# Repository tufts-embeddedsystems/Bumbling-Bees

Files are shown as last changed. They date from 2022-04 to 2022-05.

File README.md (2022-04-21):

# Bumbling-Bees

Contributors: Max Ramer, Brandon Gray, Melinda Burns, Alina Shah, Arnav Gupta, Muheng Shen

## Goal

Design, build, and program 10 temperature sensor nodes to measure temperature once an hour.  Nodes should last 6 months in the field.

## Roles

Hardware Engineers: Muheng & Arnav

Firmware Engineers: Brandon & Max

Software Engineers: Mels & Alina

## Tasks

#### Hardware

- [ ] Create an acceptance testing plan. Must test:
  
  - [ ] Sensor and thermistor
  
  - [ ] Remaining battery life
  
  - [ ] WiFi capability

- [ ] Build 1 PCB dev board

- [ ] Verify dev board functionality with testing plan

- [ ] Build and test 10 PCB dev boards

#### Firmware

- [ ] Design main program execution loop

- [ ] Collaborate with software team to finish demos

- [ ] Collaborate with hardware team to develop acceptance tests using software team demos

#### Software

- [ ] Finalize demos with firmware team:
  
  - [ ] Sensor and thermistor
  
  - [ ] Remaining battery life
  
  - [ ] WiFi & MQTT

- [ ] Write program execution loop

- [ ] Setup web server-side HTML to test MQTT messages

## 

## File structure

- `hardware/`
  
  - `pcb/`
    
    - `devboard_final/`: all KiCad files for development of the temperature node PCB. Also includes Gerber files.
  
  - `testing_plan/`: documentation for acceptance tests necessary to ensure correct PCB design.

- `PlatformIO/`: necessary files for dev environment

- `software/`
  
  - `demo/`: all code to demo individual functionality (i.e. measure temperature, connect to WiFi, enter deep sleep)
  
  - `libs/`: any necessary libraries for development
    
    `main/`: main program execution code for a node. Encompasses all demos.

## Program Execution



## Status Updates

#### Tuesday 4/26

#### Thursday 4/28

#### ...

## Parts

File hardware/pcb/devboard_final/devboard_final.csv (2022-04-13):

Source: | /Users/maxramer/Documents/Tufts/EE193/Bumbling-Bees/pcb_design/Prototype MKI/32S2_3/32S2_3.kicad_sch
Date: | Wednesday, April 13, 2022 at 10:00:36 AM
Tool: | Eeschema (6.0.1-0)
Generator: | /Applications/KiCad/KiCad.app/Contents/SharedSupport/plugins/bom_csv_grouped_by_value.py
Component Count: | 16
Individual Components:
Item | Qty | Reference(s) | Value | LibPart | Footprint | Datasheet
 |  | C1 | 10u | Device:C | Capacitor_SMD:C_0805_2012Metric_Pad1.18x1.45mm_HandSolder | ~
 |  | C2 | 0.1u | Device:C | Capacitor_SMD:C_0805_2012Metric_Pad1.18x1.45mm_HandSolder | ~
 |  | C3 | 10u | Device:C | Capacitor_SMD:C_0805_2012Metric_Pad1.18x1.45mm_HandSolder | ~
 |  | C4 | 10u | Device:C | Capacitor_SMD:C_0805_2012Metric_Pad1.18x1.45mm_HandSolder | ~
 |  | C6 | 1u | Device:C | Capacitor_SMD:C_0805_2012Metric_Pad1.18x1.45mm_HandSolder | ~
 |  | J1 | Conn_01x08 | Connector_Generic:Conn_01x08 | Connector_PinHeader_1.00mm:PinHeader_1x08_P1.00mm_Vertical | ~
 |  | L1 | 2.2u | Device:L | Inductor_SMD:L_0805_2012Metric_Pad1.05x1.20mm_HandSolder | ~
 |  | R1 | 10kΩ | Device:R_US | Resistor_SMD:R_0805_2012Metric_Pad1.20x1.40mm_HandSolder | ~
 |  | R2 | 10kΩ | Device:R_US | Resistor_SMD:R_0805_2012Metric_Pad1.20x1.40mm_HandSolder | ~
 |  | R3 | 10kΩ | Device:R_US | Resistor_SMD:R_0805_2012Metric_Pad1.20x1.40mm_HandSolder | ~
 |  | R4 | 10kΩ | Device:R_US | Resistor_SMD:R_0805_2012Metric_Pad1.20x1.40mm_HandSolder | ~
 |  | R5 | 10k | Device:R | Resistor_SMD:R_0805_2012Metric_Pad1.20x1.40mm_HandSolder | ~
 |  | U1 | AT30TS74 | Temp Sensors:AT30TS74 | Package_SO:SOIC-8_3.9x4.9mm_P1.27mm
 |  | U2 | NCU18XH103F60RB | Temp Sensors:NCU18XH103F60RB | Resistor_SMD:R_0805_2012Metric_Pad1.20x1.40mm_HandSolder
 |  | U3 | ESP32_S2_SOLO | CPU:ESP32_S2_SOLO | Module:ESP-32-S2-SOLO
 |  | U4 | RP402N331F-TR-FE | power:RP402N331F-TR-FE | Module:RP402N331F-TR-FE
Collated Components:
Item | Qty | Reference(s) | Value | LibPart | Footprint | Datasheet
1 | 3 | C1, C3, C4 | 10u | Device:C | Capacitor_SMD:C_0805_2012Metric_Pad1.18x1.45mm_HandSolder | ~
2 | 1 | C2 | 0.1u | Device:C | Capacitor_SMD:C_0805_2012Metric_Pad1.18x1.45mm_HandSolder | ~
3 | 1 | C6 | 1u | Device:C | Capacitor_SMD:C_0805_2012Metric_Pad1.18x1.45mm_HandSolder | ~
4 | 1 | J1 | Conn_01x08 | Connector_Generic:Conn_01x08 | Connector_PinHeader_1.00mm:PinHeader_1x08_P1.00mm_Vertical | ~
5 | 1 | L1 | 2.2u | Device:L | Inductor_SMD:L_0805_2012Metric_Pad1.05x1.20mm_HandSolder | ~
6 | 4 | R1, R2, R3, R4 | 10kΩ | Device:R_US | Resistor_SMD:R_0805_2012Metric_Pad1.20x1.40mm_HandSolder | ~
7 | 1 | R5 | 10k | Device:R | Resistor_SMD:R_0805_2012Metric_Pad1.20x1.40mm_HandSolder | ~
8 | 1 | U1 | AT30TS74 | Temp Sensors:AT30TS74 | Package_SO:SOIC-8_3.9x4.9mm_P1.27mm
9 | 1 | U2 | NCU18XH103F60RB | Temp Sensors:NCU18XH103F60RB | Resistor_SMD:R_0805_2012Metric_Pad1.20x1.40mm_HandSolder
10 | 1 | U3 | ESP32_S2_SOLO | CPU:ESP32_S2_SOLO | Module:ESP-32-S2-SOLO
11 | 1 | U4 | RP402N331F-TR-FE | power:RP402N331F-TR-FE | Module:RP402N331F-TR-FE

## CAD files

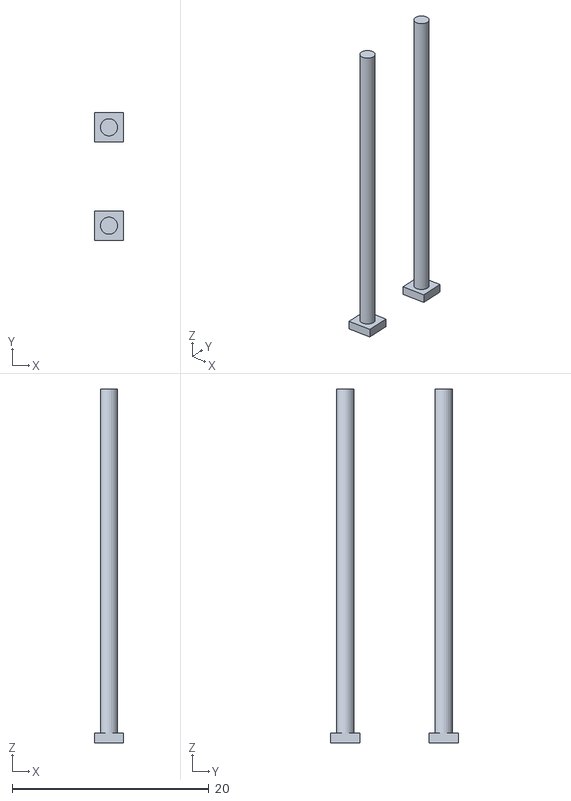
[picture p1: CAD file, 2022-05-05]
diagrams/193SencorPackaging_V2 Pins.stl
3.00 x 13.0 x 36.0

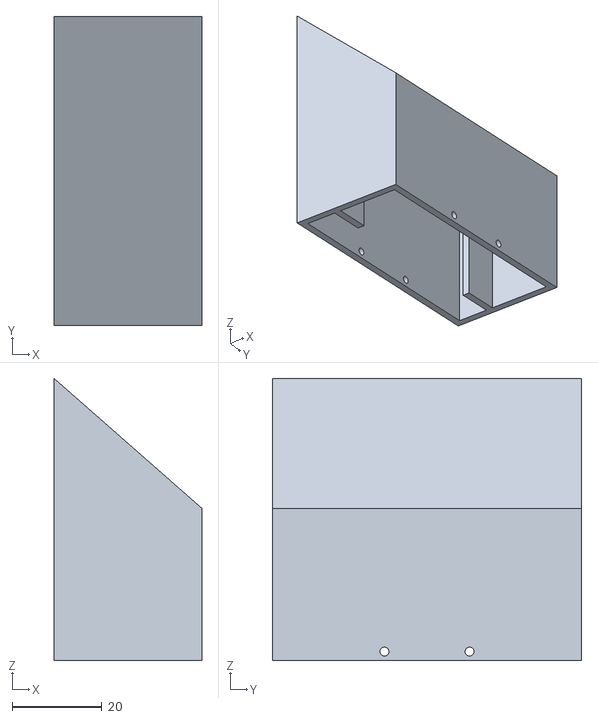
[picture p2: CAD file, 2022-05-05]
diagrams/193SencorPackaging_V2 Body.stl
33.0 x 69.0 x 63.0

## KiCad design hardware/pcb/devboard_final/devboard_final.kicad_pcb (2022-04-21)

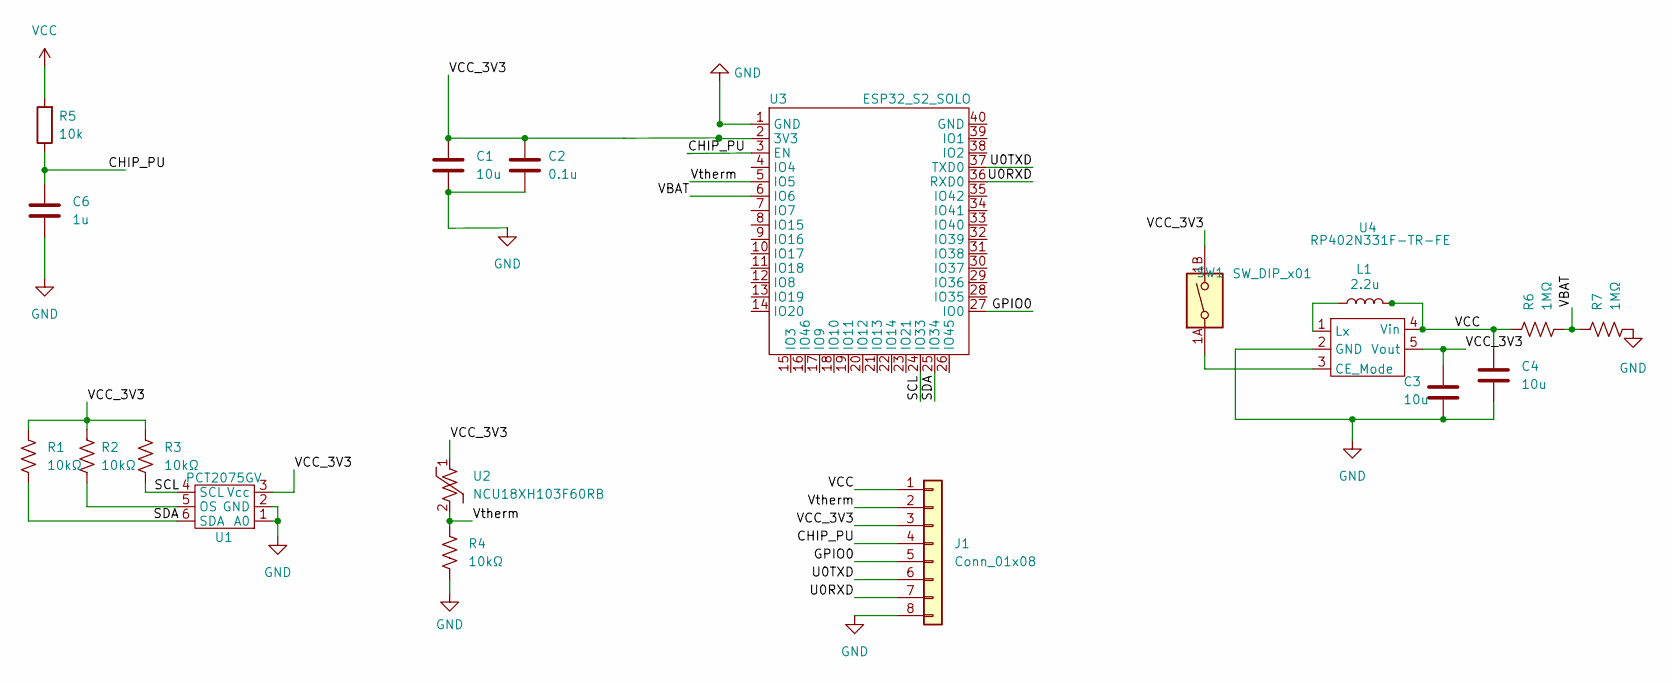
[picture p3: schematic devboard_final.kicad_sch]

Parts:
C1, C3, C4: 10u; C_0805_2012Metric_Pad1.18x1.45mm_HandSolder
C2: 0.1u; C_0805_2012Metric_Pad1.18x1.45mm_HandSolder
C6: 1u; C_0805_2012Metric_Pad1.18x1.45mm_HandSolder
J1: Conn_01x08; PinHeader_1x08_P2.54mm_Vertical
L1: 2.2u; L_0805_2012Metric_Pad1.05x1.20mm_HandSolder
R1, R2, R3, R4: 10kΩ; R_0805_2012Metric_Pad1.20x1.40mm_HandSolder
R5: 10k; R_0805_2012Metric_Pad1.20x1.40mm_HandSolder
R6, R7: 1MΩ; R_0805_2012Metric_Pad1.20x1.40mm_HandSolder
SW1: SW_DIP_x01; SW_DS04-254-1-01BK-SMT
U1: PCT2075GV; TSOP-6_1.65x3.05mm_P0.95mm
U2: NCU18XH103F60RB; R_0805_2012Metric_Pad1.20x1.40mm_HandSolder
U3: ESP32_S2_SOLO; ESP-32-S2-SOLO
U4: RP402N331F-TR-FE; SOT-23-5

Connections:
/CHIP_PU: C6.1, J1.4, R5.1, U3.3 (EN)
/GPIO0: J1.5, U3.27 (IO0)
/SCL: R3.2, U1.4 (SCL), U3.24 (IO33)
/SDA: R1.2, U1.6 (SDA), U3.25 (IO34)
/U0RXD: J1.7, U3.36 (RXD0)
/U0TXD: J1.6, U3.37 (TXD0)
/VBAT: R6.2, R7.1, U3.6 (IO6)
/VCC_3V3: C3.2, J1.3, R1.1, R2.1, R3.1, SW1.1B, U1.3 (Vcc), U2.1, U4.5 (Vout)
/Vtherm: J1.2, R4.1, U2.2, U3.5 (IO5)
GND: C1.2, C2.2, C3.1, C4.2, C6.2, J1.8, R4.2, R7.2, U1.1 (A0), U1.2 (GND), U3.1 (GND), U4.2 (GND)
unnamed: C1.1, C2.1, U3.2 (3V3)
unnamed: L1.1, U4.1 (Lx)
unnamed: R2.2, U1.5 (OS)
unnamed: SW1.1A, U4.3 (CE_Mode)
VCC: C4.1, J1.1, L1.2, R5.2, R6.1, U4.4 (Vin)

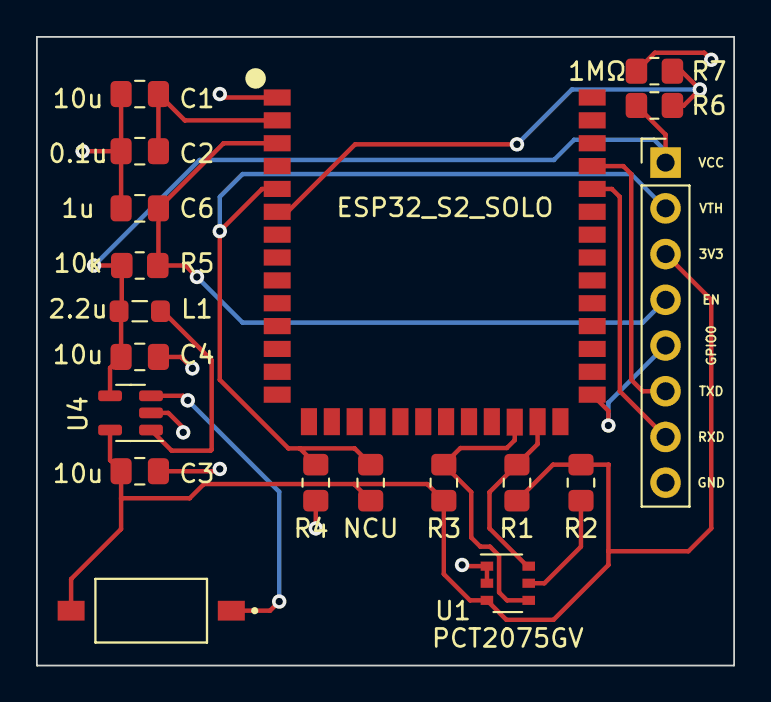
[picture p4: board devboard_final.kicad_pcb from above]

Board: 2 copper layers, 38.7 x 34.9 mm, 19 parts (0 on the bottom side), 15 nets.

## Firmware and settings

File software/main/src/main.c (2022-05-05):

// Bumbling Bees temperature sensor code
// Embedded Systems, spring 2022

#include "freertos/FreeRTOS.h"
#include "freertos/task.h"
#include "nvs_flash.h"
#include "esp_netif.h"
#include "mqtt_client.h"
#include "minimal_wifi.h"
#include "esp_sleep.h"
#include "esp_log.h"
#include <stdio.h>
#include <stdlib.h>
#include <math.h>
#include "driver/adc.h"
#include "driver/i2c.h"
#include "esp_adc_cal.h"

// Address of MQTT server
#define BROKER_URI "mqtt://en1-pi.eecs.tufts.edu"
#define NODE_PATH "nodes/bumbling-bees/node2"

//I2C SENSOR//
#define I2C_MASTER_SCL_IO           33      /*!< GPIO number used for I2C master clock */
#define I2C_MASTER_SDA_IO           34     /*!< GPIO number used for I2C master data  */
#define I2C_MASTER_NUM              0                          /*!< I2C master i2c port number, the number of i2c peripheral interfaces available will depend on the chip */
#define I2C_MASTER_FREQ_HZ          400000                     /*!< I2C master clock frequency */
#define I2C_MASTER_TX_BUF_DISABLE   0                          /*!< I2C master doesn't need buffer */
#define I2C_MASTER_RX_BUF_DISABLE   0                          /*!< I2C master doesn't need buffer */
#define I2C_MASTER_TIMEOUT_MS       1000
#define ACK_CHECK_EN 0x1                        /*!< I2C master will check ack from slave*/
#define ACK_VAL 0x0                             /*!< I2C ack value */
#define NACK_VAL 0x1                            /*!< I2C nack value */
#define SENSOR_ADDR                 0x93        /*!< Slave address of the temp sensor  1001 001*/

//THERMISTOR ADC//
#define DEFAULT_VREF 1100
#define NO_OF_SAMPLES 64 //Taking 64 samples per reading
static esp_adc_cal_characteristics_t *adc_chars;
static const adc_channel_t channel = ADC_CHANNEL_4;
static const adc_bits_width_t width = ADC_WIDTH_BIT_13;
static const adc_atten_t atten = ADC_ATTEN_DB_11;
static const adc_unit_t unit = ADC_UNIT_1;
#define T0 298.15 //Room Temp in Kelvin
#define R0 10000 //Resitor used in voltage divider
#define ThermBeta 3380.0 //Beta Constant 

//BATTERY ADC//
/*
static const adc_channel_t batt_channel = ADC_CHANNEL_5;
#define BATT_MAX_VOLTAGE 3.6
*/

// Data packet
struct packet {
	int64_t time; // Epoch time
	int32_t sensor_temp; // Temperature in C, multiplied by 1000
	int32_t thermistor_temp; // Temp in degrees C, -2^31 is unused
	uint8_t battery; // Percentage of battery capacity, 0 to 100, 255 means no battery or no measurement
	uint16_t data_len; // 0 for us
	//uint8_t teamdata[2];
} __attribute__((packed));

const int PACKET_SIZE = 8 + 4 + 4 + 1 + 2;

// Function declarations
void wifi_init(void);
static void mqtt_event_handler(void *handler_args, esp_event_base_t base, int32_t event_id, void *event_data);
uint8_t myPow(uint8_t base, uint8_t exponent);
static esp_err_t i2c_master_init(void);
static esp_err_t temp_register_read(uint8_t *data, size_t len);
float convertTemp(uint8_t data[]);
void config_ADC(void);


void app_main() {
    // Start I2C and ADC
    i2c_master_init();
    config_ADC();

    // Start wifi
    wifi_init();

    // Initialize MQTT client
    esp_mqtt_client_config_t mqtt_cfg = {
        .uri = BROKER_URI,
    };
    esp_mqtt_client_handle_t client = esp_mqtt_client_init(&mqtt_cfg);
    esp_mqtt_client_register_event(client, ESP_EVENT_ANY_ID, mqtt_event_handler, client);

    // Start the client
    esp_mqtt_client_start(client);

}


// Does some magic to make the wifi work
void wifi_init(void) {
    // `ESP_ERROR_CHECK` is a macro which checks that the return value of a function is
    // `ESP_OK`.  If not, it prints some debug information and aborts the program.

    // Enable Flash (aka non-volatile storage, NVS)
    // The WiFi stack uses this to store some persistent information
    ESP_ERROR_CHECK(nvs_flash_init());

    // Initialize the network software stack
    ESP_ERROR_CHECK(esp_netif_init());

    // Initialize the event loop, a separate thread which checks for events
    // (like WiFi being connected or receiving an MQTT message) and dispatches
    // functions to handle them.
    ESP_ERROR_CHECK(esp_event_loop_create_default());

    // Now connect to WiFi
    ESP_ERROR_CHECK(example_connect());
}


// Decides what to do when an MQTT event happens
static void mqtt_event_handler(void *handler_args, esp_event_base_t base, int32_t event_id, void *event_data)
{
    const char *TAG = "MQTT_HANDLE";
    ESP_LOGD(TAG, "Event dispatched from event loop base=%s, event_id=%d", base, event_id);
    esp_mqtt_event_handle_t event = event_data;
    esp_mqtt_client_handle_t client = event->client;
    int msg_id;
    switch ((esp_mqtt_event_id_t)event_id) {

    // Send message once connected
    case MQTT_EVENT_CONNECTED:
        ESP_LOGI(TAG, "MQTT_EVENT_CONNECTED");

        // Get IC temperature readings
        uint8_t IC_data[2];
        float IC_Temp;
        ESP_ERROR_CHECK(temp_register_read(IC_data, 2)); 
        printf("IC Temp = %d + %d\n", IC_data[0], IC_data[1]);
        IC_Temp = convertTemp(IC_data);
        printf("IC Temp = %f ˚C\n",IC_Temp);
        int ic_convert_temp = IC_Temp * 1000;
        // make sure to change the variable back

        // Get ADC temperature readings
        float ThermRes = 0;
        float ThermTempK = 0;
        float ThermTempC = 0;
        uint32_t thermReading = 0;

        for (int i = 0; i < NO_OF_SAMPLES; i++) {
            thermReading += adc1_get_raw((adc1_channel_t)channel);
        }
        thermReading /= NO_OF_SAMPLES;

        // Convert adc_reading to voltage in mV
        float voltage = esp_adc_cal_raw_to_voltage(thermReading, adc_chars);
        ThermRes = R0 * ((3300/voltage)-1);

        // Test #1 (Approx Temperature)
        ThermTempK = 1/((1/T0) + ((1/ThermBeta) * log(ThermRes/R0)));
        ThermTempC = ThermTempK - 273.15;
        printf("Temp Approx: %f K = %f ˚C\n", ThermTempK, ThermTempC);
        int therm_convert_temp = ThermTempC * 1000;

        // Get battery voltage
        /*
        int32_t battReading = 0;
        for (int i = 0; i < NO_OF_SAMPLES; i++) {
            battReading += adc1_get_raw((adc1_channel_t)batt_channel);
        }
        battReading /= NO_OF_SAMPLES;
        float batt_voltage = esp_adc_cal_raw_to_voltage(battReading, adc_chars);
        batt_voltage = ((batt_voltage * 2) / BATT_MAX_VOLTAGE) * 100; // Adjust for divider and convert to percentage
        uint8_t batt_life = batt_voltage;
        */

        // Construct packet
        struct packet data_packet = {1, ic_convert_temp, therm_convert_temp, 100, 0};
        void *data_ptr = &data_packet;

        // Send the message
        msg_id = esp_mqtt_client_publish(client, NODE_PATH, (char *)data_ptr, PACKET_SIZE, 1, 0);
        ESP_LOGI(TAG, "sent publish successful, msg_id=%d", msg_id);

        break;

    // Disconnect + go back to sleep once acknowledgement of publish recieved
    case MQTT_EVENT_PUBLISHED:
        ESP_LOGI(TAG, "MQTT_EVENT_PUBLISHED, msg_id=%d", event->msg_id);

        // Disconnect from wifi and MQTT client
        ESP_ERROR_CHECK(esp_mqtt_client_disconnect(client));
        ESP_ERROR_CHECK(example_disconnect());

        // Sleep
        uint64_t microseconds = 1000000;
        uint64_t seconds = 3600;
        uint64_t sleep_time = seconds * microseconds;
        esp_sleep_enable_timer_wakeup(sleep_time);
        esp_deep_sleep_start();
        break;

    // Log event before connect to prevent suspicious event message
    case MQTT_EVENT_BEFORE_CONNECT:
        ESP_LOGI(TAG, "MQTT_EVENT_BEFORE_CONNECT");
        break;

    // Handle other events
    default:
        ESP_LOGI(TAG, "Other event id:%d", event->event_id);
        break;
    }
}

uint8_t myPow (uint8_t base, uint8_t exponent) {

    uint8_t result = 1;

    for (uint8_t i = 0; i < exponent; i++) {
        result *= base;
    }

    return result;
}

/**
 * @brief i2c master initialization
 */
static esp_err_t i2c_master_init(void)
{
    int i2c_master_port = I2C_MASTER_NUM;

    i2c_config_t conf = {
        .mode = I2C_MODE_MASTER,
        .sda_io_num = I2C_MASTER_SDA_IO,
        .scl_io_num = I2C_MASTER_SCL_IO,
        .sda_pullup_en = GPIO_PULLUP_ENABLE,
        .scl_pullup_en = GPIO_PULLUP_ENABLE,
        .master.clk_speed = I2C_MASTER_FREQ_HZ,
    };

    i2c_param_config(i2c_master_port, &conf);

    return i2c_driver_install(i2c_master_port, conf.mode, I2C_MASTER_RX_BUF_DISABLE, I2C_MASTER_TX_BUF_DISABLE, 0);
}

/**
 * @brief Read a sequence of bytes from a temp sensor registers
 */
static esp_err_t temp_register_read(uint8_t *data, size_t len)
{   
    i2c_cmd_handle_t cmd = i2c_cmd_link_create();
    i2c_master_start(cmd);
    i2c_master_write_byte(cmd, SENSOR_ADDR, ACK_CHECK_EN); //0x93 is the slave address hardcoded (the 1 in the LSB tells that it's a read)
    if (len > 1) {
        i2c_master_read(cmd, data, len - 1, ACK_VAL);
    }
    i2c_master_read_byte(cmd, data + len - 1, NACK_VAL);
    i2c_master_stop(cmd);
    esp_err_t ret = i2c_master_cmd_begin(I2C_MASTER_NUM, cmd, I2C_MASTER_TIMEOUT_MS / portTICK_PERIOD_MS);
    i2c_cmd_link_delete(cmd);
    return ret;
}


float convertTemp (uint8_t data[]) {

    float tempData = 0.0;
    uint8_t temp;

    if (data[0] < 128 ) { //MSB is 0 (positive temp)

        temp = data[0]; 
        for (uint8_t i = 0; i < 8; i++) {
            tempData += (temp % 2) * myPow(2,i);
            temp /= 2;
        }

        temp = data[1];
        temp /= 32; //Turns byte into most significant 3 bits
        if ((temp % 2) == 1) { //0.125
            tempData += 0.125;
        }
        temp /= 2;
        if ((temp % 2) == 1) { //0.25
            tempData += 0.25;
        }
        temp /= 2;
        if ((temp % 2) == 1) { //0.5
            tempData += 0.5;
        }

    } else { //LSB is 1 (negative temp)
        int16_t bits = 0xff00 | data[0]; //Sign Extended the temp in binary
        bits = bits << 3; //Shift over by 4 bits to allow for decimal of Temp
        temp = data[1];
        temp /= 32; //Turns byte into most significant 3 bits
        if ((temp % 2) == 1) { //0.125
            bits |= 1 << 0;
        }
        temp /= 2;
        if ((temp % 2) == 1) { //0.25
            bits |= 1 << 1;
        }
        temp /= 2;
        if ((temp % 2) == 1) { //0.5
            bits |= 1 << 2;
        }
        tempData = bits;
        tempData /= 8; 
    }
    return tempData;
}

void config_ADC(void) {
    //Configure ADC
    adc1_config_width(width);
    adc1_config_channel_atten(channel, atten);

    //Characterize ADC
    adc_chars = calloc(1, sizeof(esp_adc_cal_characteristics_t));
    esp_adc_cal_characterize(unit, atten, width, DEFAULT_VREF, adc_chars);
}

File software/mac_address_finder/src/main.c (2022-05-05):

/* Base mac address example
 This example code is in the Public Domain (or CC0 licensed, at your option.)
 Unless required by applicable law or agreed to in writing, this
 software is distributed on an "AS IS" BASIS, WITHOUT WARRANTIES OR
 CONDITIONS OF ANY KIND, either express or implied.
 */

#include <stdlib.h>
#include <string.h>
#include "esp_log.h"
#include "esp_system.h"

#define TAG "BASE_MAC"

#ifdef CONFIG_BASE_MAC_STORED_OTHER_EXTERNAL_STORAGE

static esp_err_t external_storage_mac_get(uint8_t *mac)
{
    /* This function simulates getting a base MAC address from external storage
     * by simply setting the base MAC to an arbitrary address. Users should
     * re-implement this function to access external storage (e.g. flash, EEPROM) */
    uint8_t external_storage_mac_addr[6] = { 0x00, 0x11, 0x22, 0x33, 0x44, 0x55 };
    if (mac == NULL) {
        ESP_LOGE(TAG, "The mac parameter is NULL");
        abort();
    }

    memcpy(mac, external_storage_mac_addr, 6);
    return ESP_OK;
}
#endif//CONFIG_BASE_MAC_STORED_OTHER_EXTERNAL_STORAGE

void app_main(void)
{
    //Get the base MAC address from different sources
    uint8_t base_mac_addr[6] = {0};
    esp_err_t ret = ESP_OK;
#ifdef CONFIG_BASE_MAC_STORED_EFUSE_BLK3
    //Get base MAC address from EFUSE BLK3
    ret = esp_efuse_mac_get_custom(base_mac_addr);
    if (ret != ESP_OK) {
        ESP_LOGE(TAG, "Failed to get base MAC address from EFUSE BLK3. (%s)", esp_err_to_name(ret));
#ifdef CONFIG_BASE_MAC_STORED_EFUSE_BLK3_ERROR_ABORT
        ESP_LOGE(TAG, "Aborting");
        abort();
#else
        ESP_LOGI(TAG, "Defaulting to base MAC address in BLK0 of EFUSE");
        esp_efuse_mac_get_default(base_mac_addr);
        ESP_LOGI(TAG, "Base MAC Address read from EFUSE BLK0");
#endif//CONFIG_BASE_MAC_STORED_EFUSE_BLK3_ERROR_ABORT
    } else {
        ESP_LOGI(TAG, "Base MAC Address read from EFUSE BLK3");
    }
#elif defined(CONFIG_BASE_MAC_STORED_OTHER_EXTERNAL_STORAGE)
    //Get base MAC address from other external storage, or set by software
    ret = external_storage_mac_get(base_mac_addr);
    if (ret != ESP_OK) {
        ESP_LOGE(TAG, "Failed to get base MAC address from external storage. (%s)", esp_err_to_name(ret));
        ESP_LOGE(TAG, "Aborting");
        abort();
    } else {
        ESP_LOGI(TAG, "Base MAC Address read from external storage");
    }
#else
    //Get base MAC address from EFUSE BLK0(default option)
    ret = esp_efuse_mac_get_default(base_mac_addr);
    if (ret != ESP_OK) {
        ESP_LOGE(TAG, "Failed to get base MAC address from EFUSE BLK0. (%s)", esp_err_to_name(ret));
        ESP_LOGE(TAG, "Aborting");
        abort();
    } else {
        ESP_LOGI(TAG, "Base MAC Address read from EFUSE BLK0");
    }
#endif

    //Set the base MAC address using the retrieved MAC address
    ESP_LOGI(TAG, "Using \"0x%x, 0x%x, 0x%x, 0x%x, 0x%x, 0x%x\" as base MAC address",
             base_mac_addr[0], base_mac_addr[1], base_mac_addr[2], base_mac_addr[3], base_mac_addr[4], base_mac_addr[5]);
    esp_base_mac_addr_set(base_mac_addr);

    //Get the derived MAC address for each network interface
    uint8_t derived_mac_addr[6] = {0};
    //Get MAC address for WiFi Station interface
    ESP_ERROR_CHECK(esp_read_mac(derived_mac_addr, ESP_MAC_WIFI_STA));
    ESP_LOGI("WIFI_STA MAC", "0x%x, 0x%x, 0x%x, 0x%x, 0x%x, 0x%x",
             derived_mac_addr[0], derived_mac_addr[1], derived_mac_addr[2],
             derived_mac_addr[3], derived_mac_addr[4], derived_mac_addr[5]);

    //Get MAC address for SoftAp interface
    ESP_ERROR_CHECK(esp_read_mac(derived_mac_addr, ESP_MAC_WIFI_SOFTAP));
    ESP_LOGI("SoftAP MAC", "0x%x, 0x%x, 0x%x, 0x%x, 0x%x, 0x%x",
             derived_mac_addr[0], derived_mac_addr[1], derived_mac_addr[2],
             derived_mac_addr[3], derived_mac_addr[4], derived_mac_addr[5]);

#if CONFIG_ESP_MAC_ADDR_UNIVERSE_BT
    //Get MAC address for Bluetooth
    ESP_ERROR_CHECK(esp_read_mac(derived_mac_addr, ESP_MAC_BT));
    ESP_LOGI("BT MAC", "0x%x, 0x%x, 0x%x, 0x%x, 0x%x, 0x%x",
             derived_mac_addr[0], derived_mac_addr[1], derived_mac_addr[2],
             derived_mac_addr[3], derived_mac_addr[4], derived_mac_addr[5]);
#endif //SOC_BT_SUPPORTED

    //Get MAC address for Ethernet
    ESP_ERROR_CHECK(esp_read_mac(derived_mac_addr, ESP_MAC_ETH));
    ESP_LOGI("Ethernet MAC", "0x%x, 0x%x, 0x%x, 0x%x, 0x%x, 0x%x",
             derived_mac_addr[0], derived_mac_addr[1], derived_mac_addr[2],
             derived_mac_addr[3], derived_mac_addr[4], derived_mac_addr[5]);
}

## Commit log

2022-04-11 added comments and organization
    [32S2_1.kicad_pcb, 32S2_1.kicad_sch, 32S2_2.kicad_pcb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]
2022-04-12 Updated ESP32-S2 chip
    [32S2_3.kicad_sch, Project1.kicad_sch]
2022-04-12 Added voltage regulator to schematic
    [32S2_1.kicad_pcb, 32S2_1.kicad_sch, 32S2_2.kicad_pcb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]
2022-04-13 finalized PCB
    [32S2_3.kicad_sch]
2022-04-13 Finalized schematic
    [32S2_3.csv, 32S2_3.kicad_pcb, 32S2_3.kicad_sch]
2022-04-13 Added Programming board
    [32S2_3.kicad_pcb, Programming Board.kicad_pcb, Programming Board.kicad_sch]
2022-04-13 v1 of PCB layout done
    [32S2_3.csv, 32S2_3.kicad_pcb, 32S2_3.kicad_sch]
2022-04-21 organized file structure, added descriptive README
    [32S2_1.kicad_pcb, 32S2_1.kicad_sch, 32S2_2.kicad_pcb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]
2022-05-04 Changed test battery level
